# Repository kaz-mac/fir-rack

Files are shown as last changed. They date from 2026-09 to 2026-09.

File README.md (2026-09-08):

# FIR RACK - 3D-printable 10-inch server rack

**English** | [日本語](./README-ja.md)

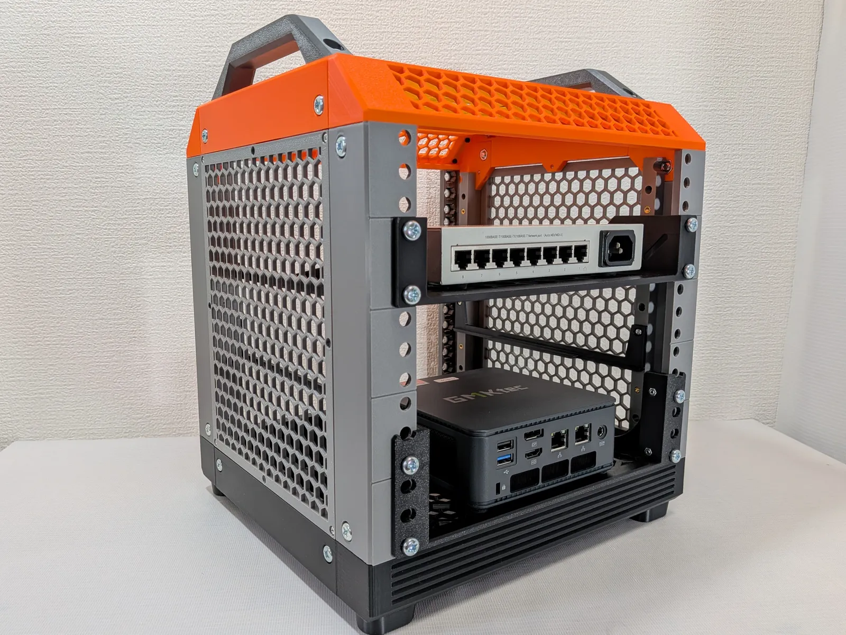
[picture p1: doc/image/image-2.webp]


## Overview

FIR RACK is a remix of [Lab Rax](https://makerworld.com/en/models/1294480-lab-rax-10-server-rack-5u#profileId-1325352) by mklements. It takes after Lab Rax in ease of assembly and overall look, but it was designed from scratch. It is not compatible with Lab Rax.

## Features

FIR RACK keeps what makes Lab Rax great, with these improvements:

* Side panels can be removed without taking the rack apart
* Nuts on the mounting rails are easy to install and remove
* More stable feet
* Deeper frame: 240 mm → 260 mm
* Support rails for heavy shelves (optional)

## Expandability

* **Rack height**<br>
    FIR RACK is 5U. With the extension kit you can add 3U or 5U. For example, adding 3U to a 5U rack gives you an 8U rack.
* **Support rails**<br>
    For heavy shelves, the optional support rails take the load off the mounting rails.

## 4 print profiles

FIR RACK has four profiles. For a minimal rack, the BASIC profile is all you need.

| Profile | What's included | Notes |
|---|---|---|
| BASIC | Core frame parts | Required |
| PANEL | Top, bottom, and side panels | Optional |
| EXTEND | Extension kit parts | Optional |
| RAIL | Support rails | Optional |

## Hardware

Parts you need to assemble FIR RACK:

| Part | Qty | Notes |
|---|---:|---|
| M6 nuts | 24 | Required |
| M6 pan-head screws, 12 mm | 24 | Required |
| M3 nuts | 16 | For side panels (optional) |
| M3 pan-head screws, 12 mm | 16 | For side panels (optional) |
| M6 nuts | 8 | For the extension kit (optional) |
| M6 pan-head screws, 12 mm | 8 | For the extension kit (optional) |
| M3 nuts | 12 | For the extension kit (optional) |
| M3 heat-set inserts (OD 5 mm, length 4 mm) | 32 | For support rails (optional) |
| M3 screws, 5 mm | 12 | For support rails (optional) |

You will also need extra M6 nuts and 12 mm M6 screws for the shelves you install.

### Budget-friendly places to buy

* M6 nuts: [Amazon](https://www.amazon.co.jp/dp/B002A5NN3O)
* M6 pan-head screws, 12 mm: [Amazon](https://www.amazon.co.jp/dp/B002A5MHGS)
* M3 heat-set inserts (OD 5 mm, length 4 mm): [Amazon](https://www.amazon.co.jp/dp/B0F5HMVBWJ) [AliExpress](https://ja.aliexpress.com/item/1005008301059667.html)

## Download the 3D models

FIR RACK is available on MakerWorld.<br>
https://makerworld.com/en/models/3273170-fir-rack-3d-printable-10-inch-server-rack

Shelves can be downloaded from this repository.<br>
[shelf/](shelf/)

If you remix FIR RACK, do not add it as a profile on this model. Publish the remix on your own MakerWorld account.

## Assembly

We recommend printing in PETG. PLA may deform in high heat. See the assembly guide:

Assembly: [English](doc/assembly-en.md) | [日本語](doc/assembly-ja.md)

## Files in GitHub repository

This repository includes:

* [Shelf 3D models](shelf/)

## FIR RACK Satisfactory Kit

A kit of replacement parts that give FIR RACK a [Satisfactory](https://store.steampowered.com/app/526870/Satisfactory/) look. Designed for multi-color printing with AMS. [→ Download](https://makerworld.com/en/models/3277142-fir-rack-satisfactory-kit#profileId-3716643)

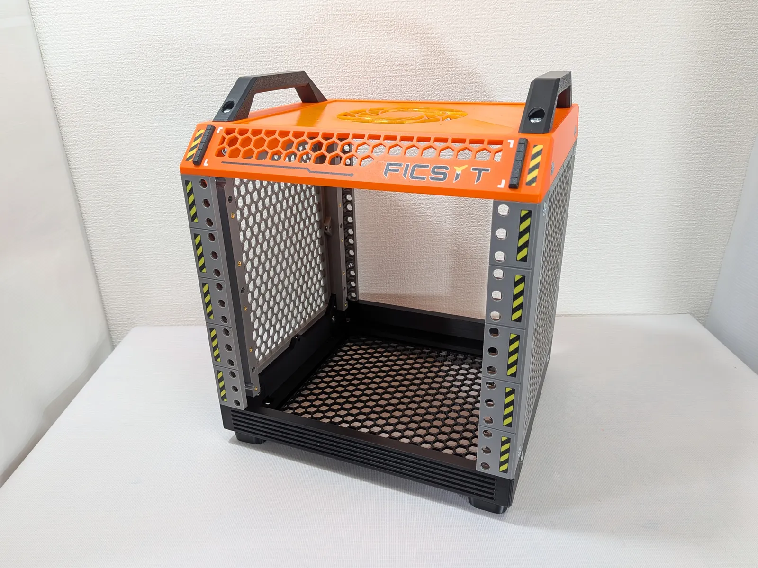
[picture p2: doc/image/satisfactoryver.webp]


## What does FIR RACK stand for?

Factory + Industry + Rig = FIR RACK

## License

The FIR RACK models on MakerWorld are licensed under the [MakerWorld Exclusive License](https://makerworld.com/en/exclusive-model-policy). You may create derivative works based on this object, provided that all such derivative works are published exclusively on the MakerWorld platform and include proper attribution to the original creator. You may not share, upload, host, distribute, or publish this object—or any derivative work of this object—on any other digital platform, marketplace, or distribution channel. Commercial use of this object and any derivative works is strictly prohibited. This includes, but is not limited to, selling, renting, sublicensing, or using the object in any context in which you receive monetary compensation or other financial benefits.

3D models published on GitHub are licensed under CC-BY-SA unless otherwise specified.

## Credits

FIR RACK is a remix of [Lab Rax](https://makerworld.com/en/models/1294480-lab-rax-10-server-rack-5u#profileId-1325352) by mklements. Thanks to mklements for the original design.

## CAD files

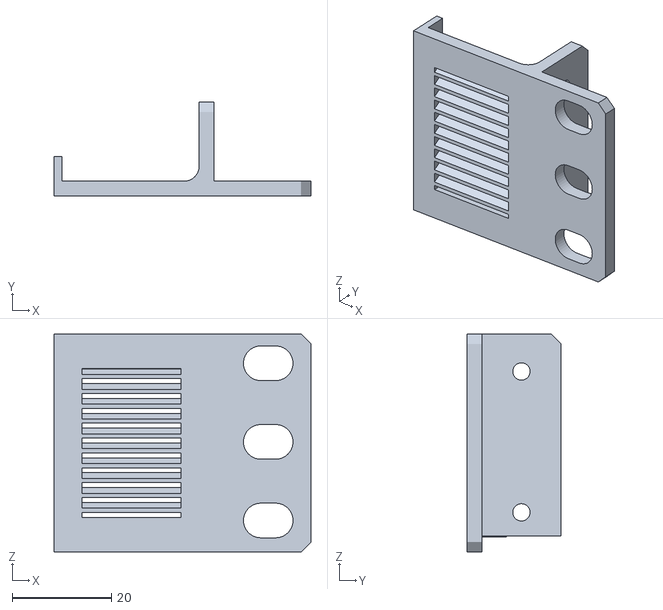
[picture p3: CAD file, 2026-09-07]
shelf/5-inch_drive_1U/1U Ear-R.stl
51.9 x 19.0 x 44.0

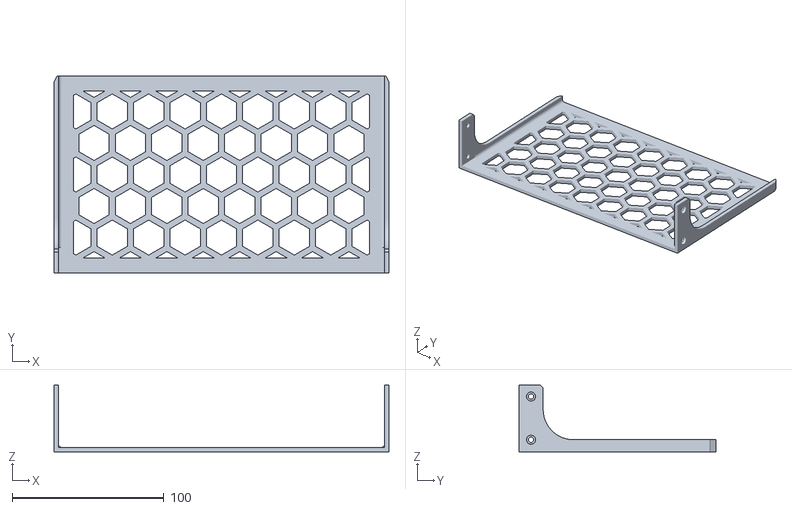
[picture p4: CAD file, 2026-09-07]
shelf/template/depth_130mm/1U Shelf.stl
220.8 x 130.0 x 44.0

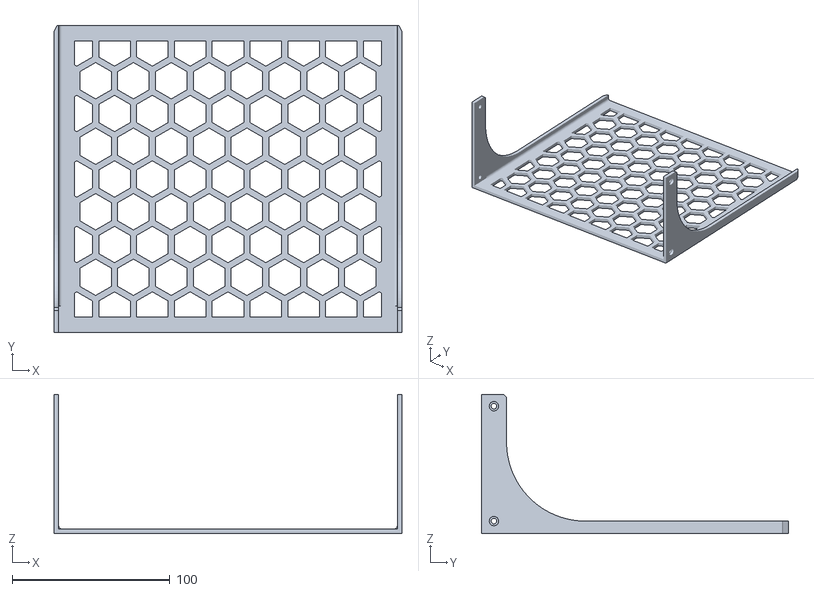
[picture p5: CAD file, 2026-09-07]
shelf/template/depth_195mm/2U Shelf.stl
220.8 x 195.0 x 88.5

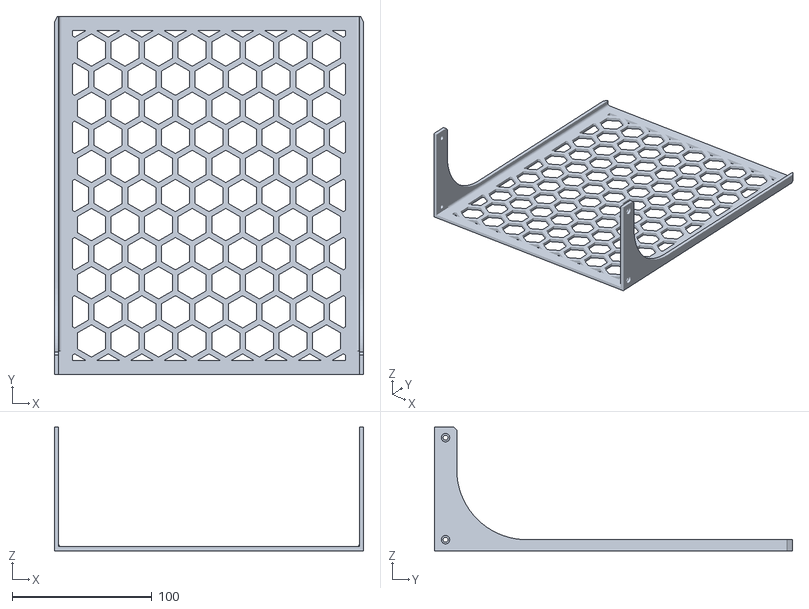
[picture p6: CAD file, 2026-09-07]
shelf/template/depth_256mm/2U Shelf.stl
220.8 x 256.0 x 88.5

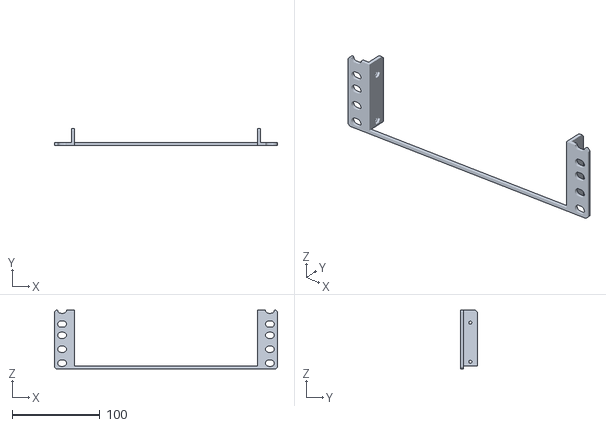
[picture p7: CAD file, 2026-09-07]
shelf/template/depth_260mm/1.5U-DW Ear.stl
253.8 x 19.0 x 66.6

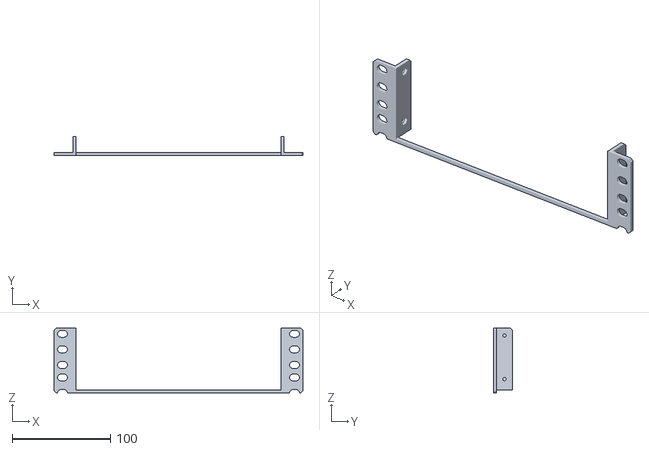
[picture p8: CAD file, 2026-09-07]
shelf/template/depth_130mm/1.5U-UP Ear.stl
253.8 x 19.0 x 66.1

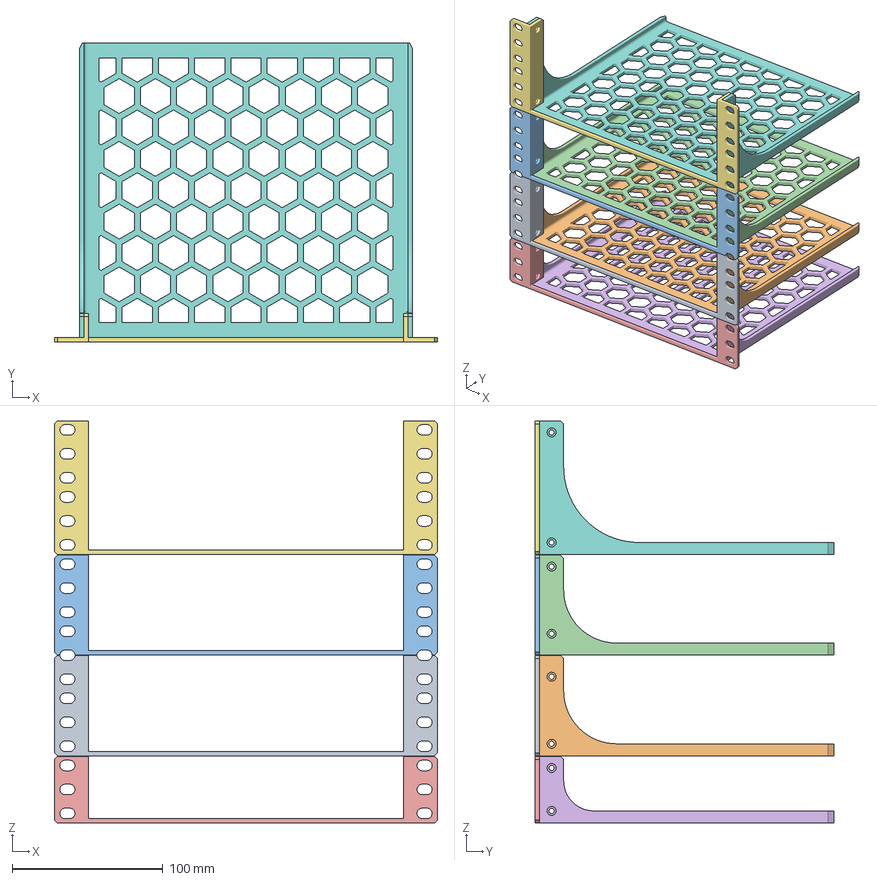
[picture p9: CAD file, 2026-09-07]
shelf/template/depth_195mm/195mm.3mf
253.8 x 198.0 x 266.3 mm
1.5U-DW Ear
1.5U-DW Shelf
1.5U-UP Ear
1.5U-UP Shelf
1U Ear
1U Shelf
2U Ear
2U Shelf

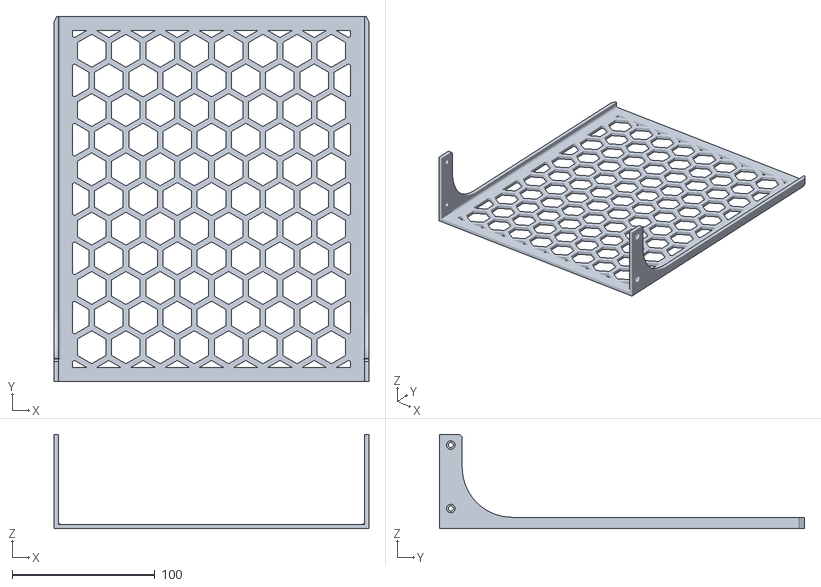
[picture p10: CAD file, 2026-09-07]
shelf/template/depth_256mm/1.5U-UP Shelf.stl
220.8 x 256.0 x 66.1

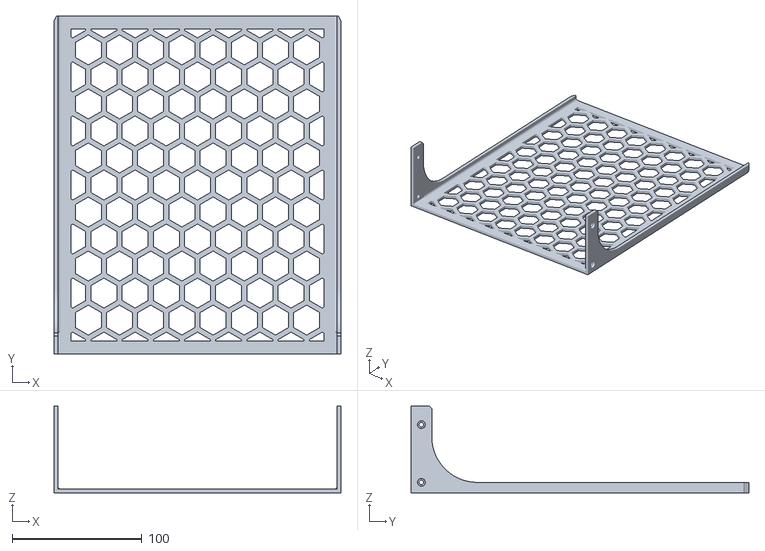
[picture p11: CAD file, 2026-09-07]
shelf/template/depth_260mm/1.5U-DW Shelf.stl
220.8 x 260.0 x 66.6

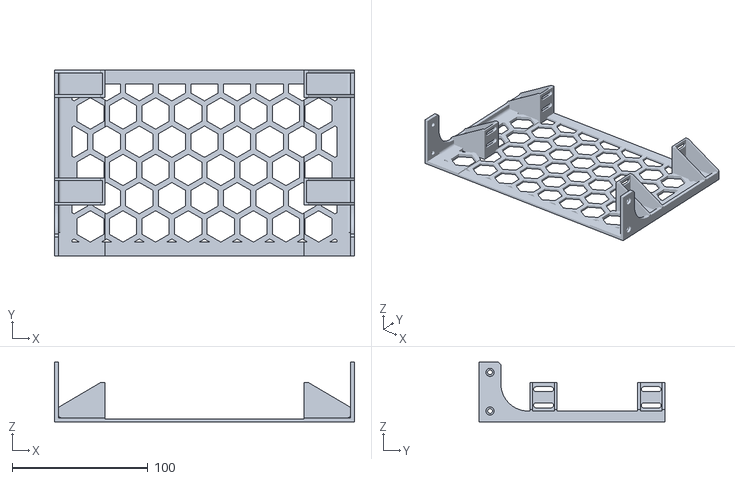
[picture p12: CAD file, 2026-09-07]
shelf/5-inch_drive_1U/1U Shelf.stl
220.8 x 136.6 x 44.0

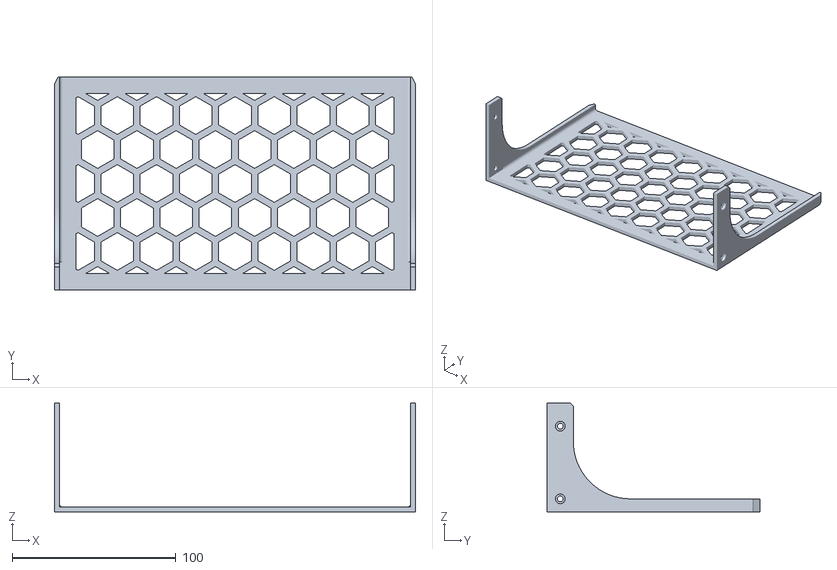
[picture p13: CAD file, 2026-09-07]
shelf/template/depth_130mm/1.5U-DW Shelf.stl
220.8 x 130.0 x 66.6

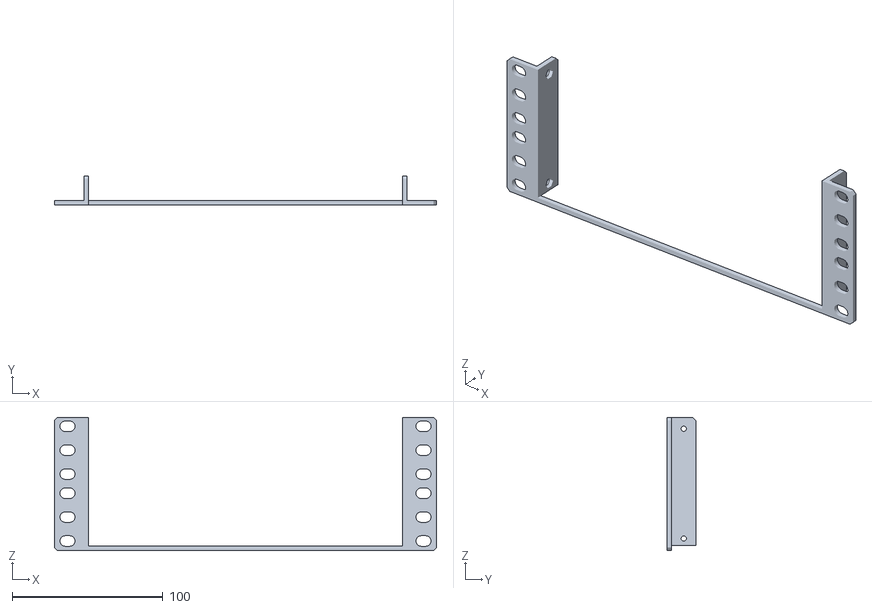
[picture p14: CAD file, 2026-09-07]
shelf/template/depth_195mm/2U Ear.stl
253.8 x 19.0 x 88.5

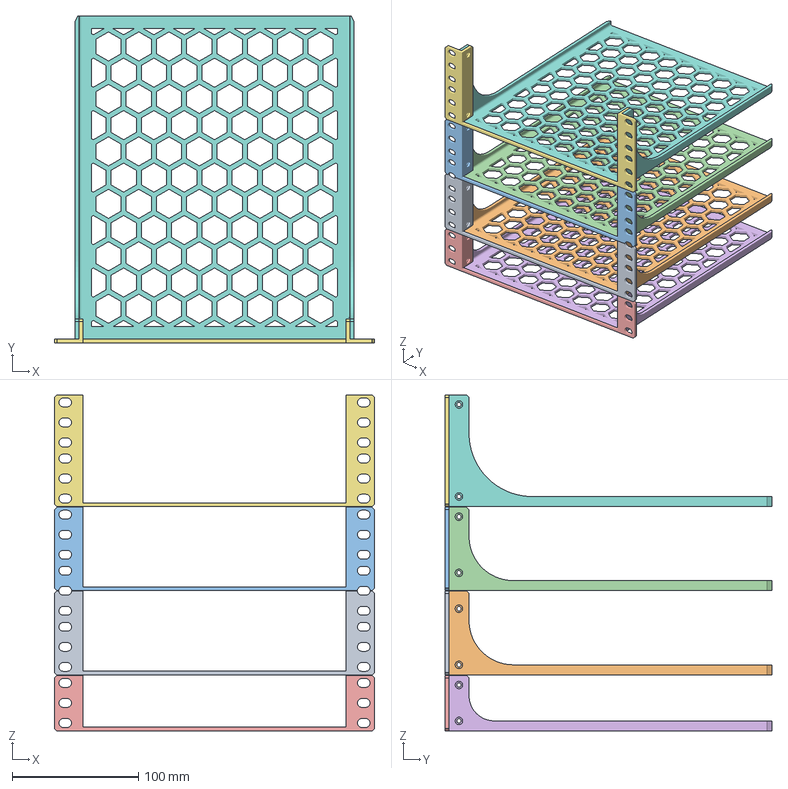
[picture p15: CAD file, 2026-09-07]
shelf/template/depth_256mm/256mm.3mf
253.8 x 259.0 x 266.3 mm
1.5U-DW Ear
1.5U-DW Shelf
1.5U-UP Ear
1.5U-UP Shelf
1U Ear
1U Shelf
2U Ear
2U Shelf

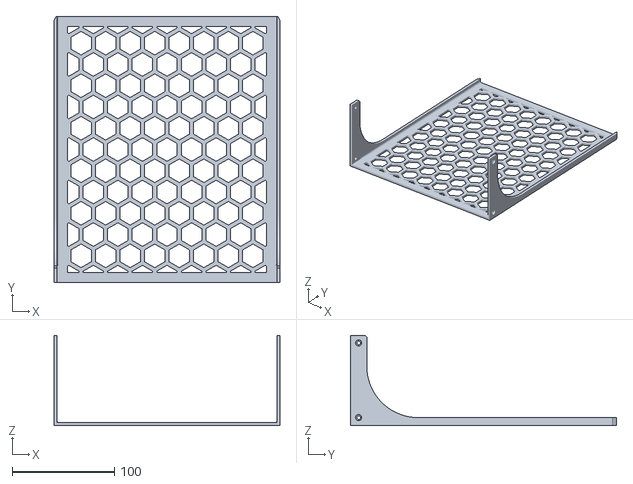
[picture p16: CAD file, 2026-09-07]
shelf/template/depth_260mm/2U Shelf.stl
220.8 x 260.0 x 88.5

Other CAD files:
shelf/5-inch_drive_1U/1U Ear-L.stl
shelf/template/depth_130mm/2U Shelf.stl
shelf/template/depth_195mm/1U Shelf.stl
shelf/template/depth_256mm/2U Ear.stl
shelf/template/depth_130mm/1.5U-DW Ear.stl
shelf/template/depth_130mm/1.5U-UP Shelf.stl
shelf/template/depth_130mm/130mm.3mf
shelf/template/depth_130mm/1U Ear.stl
shelf/template/depth_130mm/2U Ear.stl
shelf/template/depth_195mm/1.5U-DW Ear.stl
shelf/template/depth_195mm/1.5U-DW Shelf.stl
shelf/template/depth_195mm/1.5U-UP Ear.stl
shelf/template/depth_195mm/1.5U-UP Shelf.stl
shelf/template/depth_195mm/1U Ear.stl
shelf/template/depth_256mm/1.5U-DW Ear.stl
shelf/template/depth_256mm/1.5U-DW Shelf.stl
shelf/template/depth_256mm/1.5U-UP Ear.stl
shelf/template/depth_256mm/1U Ear.stl
shelf/template/depth_256mm/1U Shelf.stl
shelf/template/depth_260mm/1.5U-UP Ear.stl
shelf/template/depth_260mm/1.5U-UP Shelf.stl
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

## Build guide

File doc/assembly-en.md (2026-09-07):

# FIR RACK assembly guide

Assembly: **English** | [日本語](./assembly-ja.md)

We recommend printing in PETG. PLA may deform in high heat.

## 4 profiles

The parts you print depend on how you want to build your rack. When you open the 3MF in Bambu Studio, the top of each plate shows print quantities and other notes — use that as a reference.

### (1) BASIC profile

All of the core frame parts are in the BASIC profile.

| File name | Description | Qty | Notes |
|---|---|---:|---|
| X Edge Top | Horizontal frame, top | 2 |  |
| X Edge Bottom | Horizontal frame, bottom | 2 |  |
| Y Edge | Depth frame (rear) | 4 |  |
| Z Edge 5U | Vertical mounting rail | 4 |  |
| Handle | Handle | 2 |  |
| Foot | Foot | 4 |  |

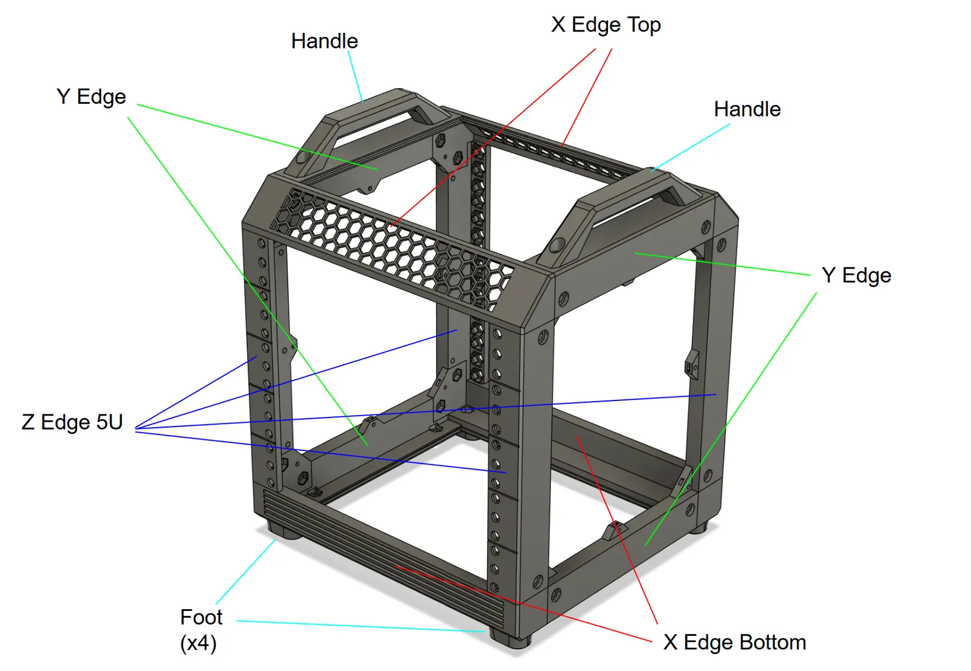
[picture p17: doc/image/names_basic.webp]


### (2) PANEL profile (optional)

Panels are in a separate profile. Print what you need from the PANEL profile.

| File name | Description |
|---|---|
| TB Panel 12cm-fan | Top/bottom panel (120 mm fan) |
| TB Panel 14cm-fan | Top/bottom panel (140 mm fan) |
| TB Panel mesh | Top/bottom panel (mesh) |
| TB Panel plane | Top/bottom panel (solid) |
| LR Panel mesh 5U | Side panel (mesh) |
| LR Panel plane 5U | Side panel (solid) |

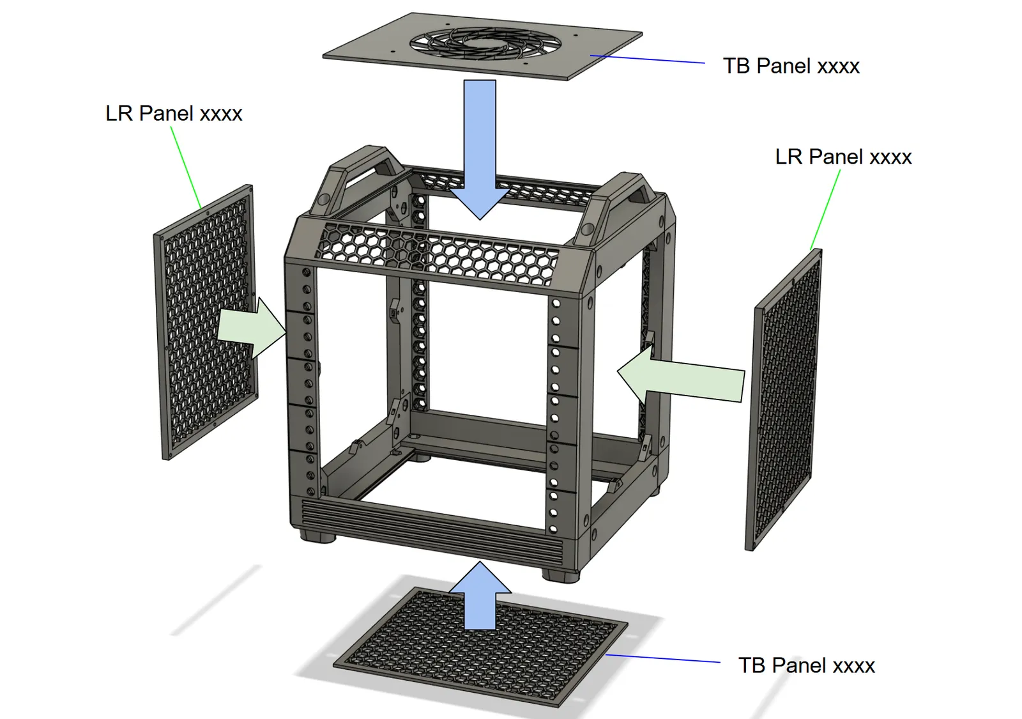
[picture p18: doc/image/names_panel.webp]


### (3) EXTEND profile (optional)

To add 3U or 5U of height, print what you need from the EXTEND profile. Parts labeled "3U" are for a 3U extension. For a 5U extension, use parts from BASIC and PANEL.

| File name | Description | 3U | 5U |
|---|---|---:|---:|
| Extend Unit | Extension unit | 2 | 2 |
| Extend Unit-cover | Extension unit screw covers | 6 | 6 |
| Z Edge 3U | Vertical mounting rail, 3U | 4 |  |
| Rail Holder-L 3U | Support rail bracket, left, 3U | (2) *1 |  |
| Rail Holder-R 3U | Support rail bracket, right, 3U | (2) *1 |  |
| LR Panel mesh 3U | Side panel (mesh), 3U | (2) |  |
| LR Panel plane 3U | Side panel (solid), 3U | (2) |  |

Note: *1 ... Print only if you use support rails

For details, see [Assembling the extension kit](#assembling-the-extension-kit) in this guide.

### (4) RAIL profile (optional)

Support rails are optional. They can hold heavy shelves, but only certain shelves will fit. See [Using the support rails](#using-the-support-rails-optional) in this guide.

| File name | Description | Qty | Notes |
|---|---|---:|---|
| Rail Holder-L 5U | Support rail bracket, left | (2) | *1 |
| Rail Holder-R 5U | Support rail bracket, right | (2) | *1 |
| Rail-1U | Support rail (1U) | (2 per U) | *1 |
| Rail-1.5U | Support rail (1.5U) | (2 per U) | *1 |

Note: *1 ... Print only if you use support rails

For details, see [Using the support rails](#using-the-support-rails-optional) in this guide.

## STEP 1 Installing the nuts

After printing, take the X Edge Top/Bottom, Y Edge, and Z Edge 5U parts.
Press-fit the M3 nuts used to mount the panels.

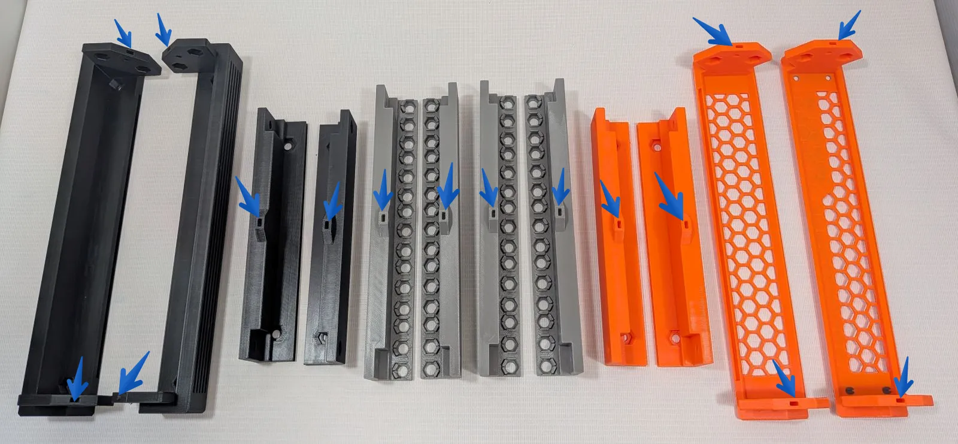
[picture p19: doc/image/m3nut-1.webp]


Push them all the way in with a flat-head screwdriver or a thin rod.

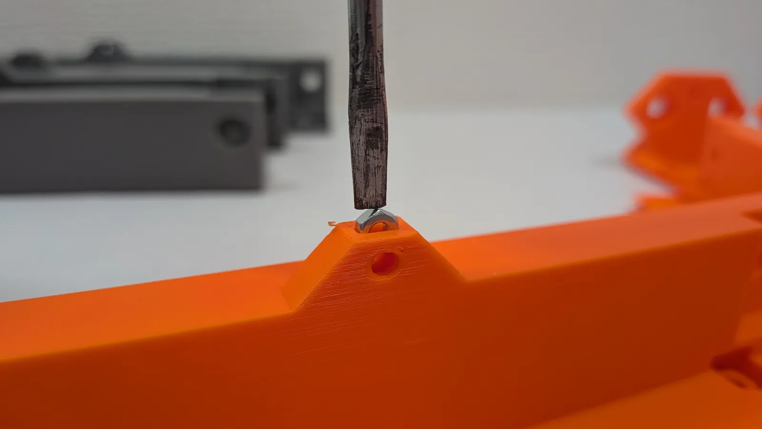
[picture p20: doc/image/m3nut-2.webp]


## STEP 2 Assembling the bottom

Assemble the bottom frame. Fit X Edge Bottom and Y Edge together, and slide in the TB Panel you chose. Watch the direction of the panel grooves. Once everything is seated, fasten with M6 nuts and M6 screws. If a nut is too tight, use pliers. If it is loose, a small amount of glue helps.

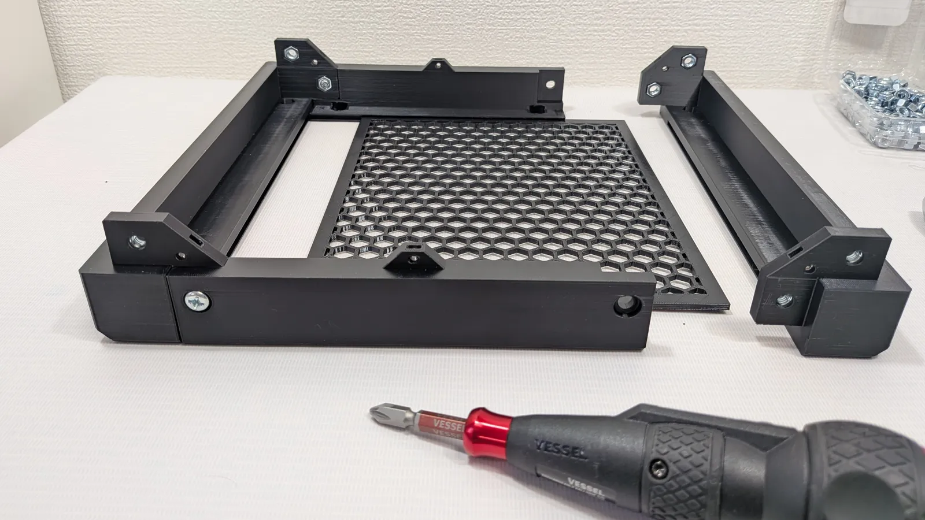
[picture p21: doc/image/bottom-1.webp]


Flip it over and install the Foot parts. Do not use the inner holes.

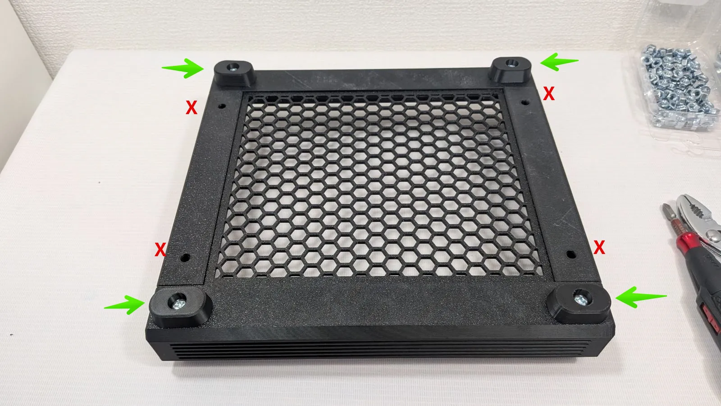
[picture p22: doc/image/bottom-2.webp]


## STEP 3 Assembling the top

Assemble the top frame. Fit X Edge Top and Y Edge together, and slide in the TB Panel you chose.

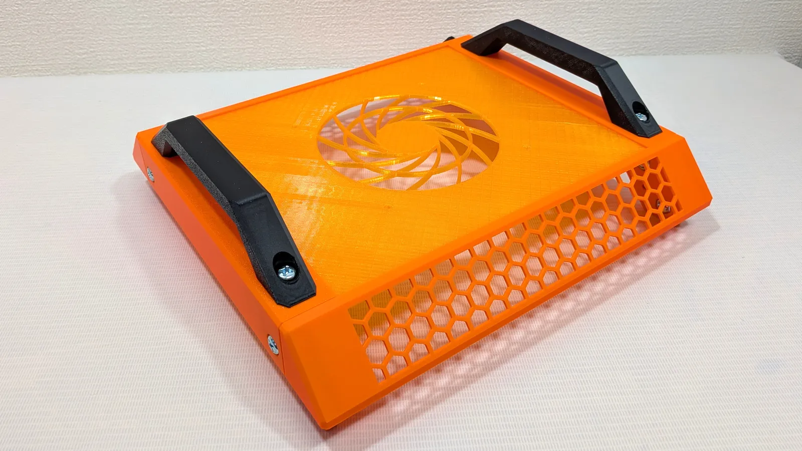
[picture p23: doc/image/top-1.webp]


Then install the Handle parts.

## STEP 4 Support rails (optional)

If you are not using support rails, skip to STEP 5. Support rails can hold heavy shelves. If you use them, you need to prep the mounting rails before final assembly.

### Installing heat-set inserts

Install heat-set inserts in Z Edge 5U, Rail Holder-L 5U, and Rail Holder-R 5U. Use the smaller holes.

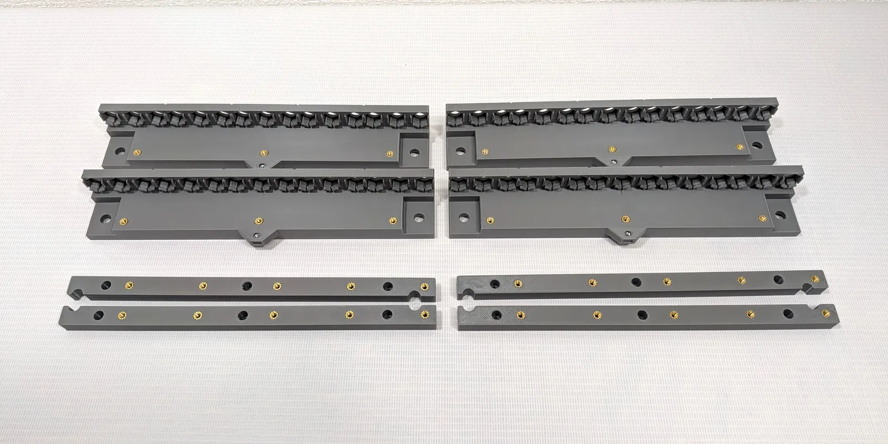
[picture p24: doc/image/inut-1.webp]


Insert size: ID 3 mm, OD 5 mm, length 4 mm

### Attaching the rail holders

Attach the Rail Holder-* 5U parts to Z Edge 5U. Fasten with M3 × 5 mm screws. Watch the orientation: arrange them as in the photo, with the ▼ marks pointing down.

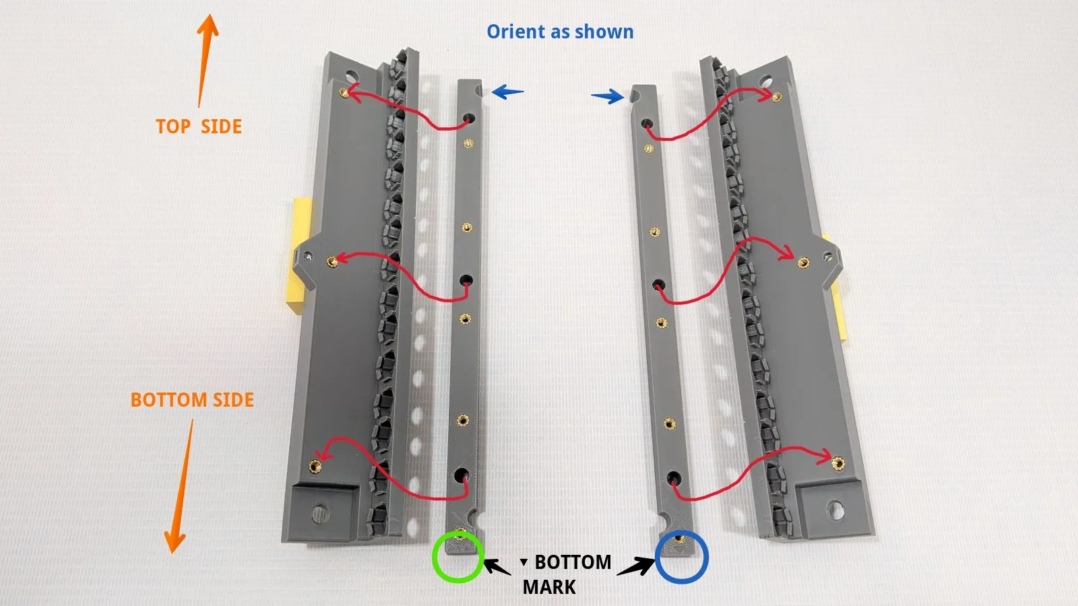
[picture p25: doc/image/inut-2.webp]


Finished assembly:

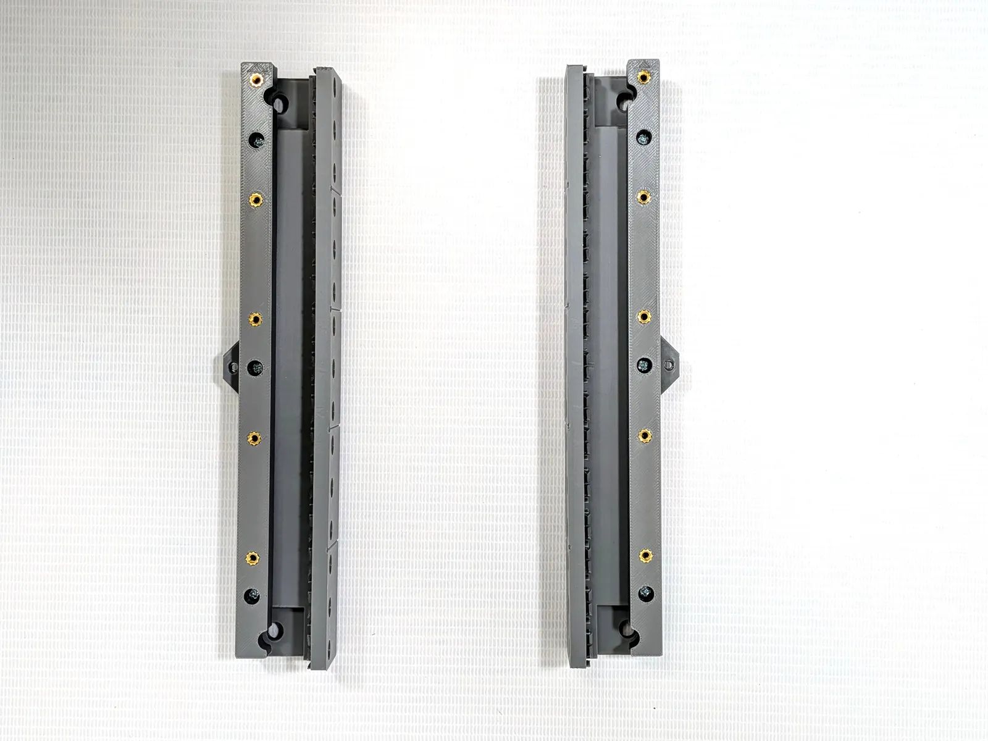
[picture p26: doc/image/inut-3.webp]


If the M6 screw holes are blocked, the parts are on the wrong side. Compare with the photo and flip them.

## STEP 5 Putting the rack together

Connect the bottom frame to the mounting rails (Z Edge 5U) with M6 × 12 mm screws. Insert the nuts first, set the rail position, then tighten the screws.

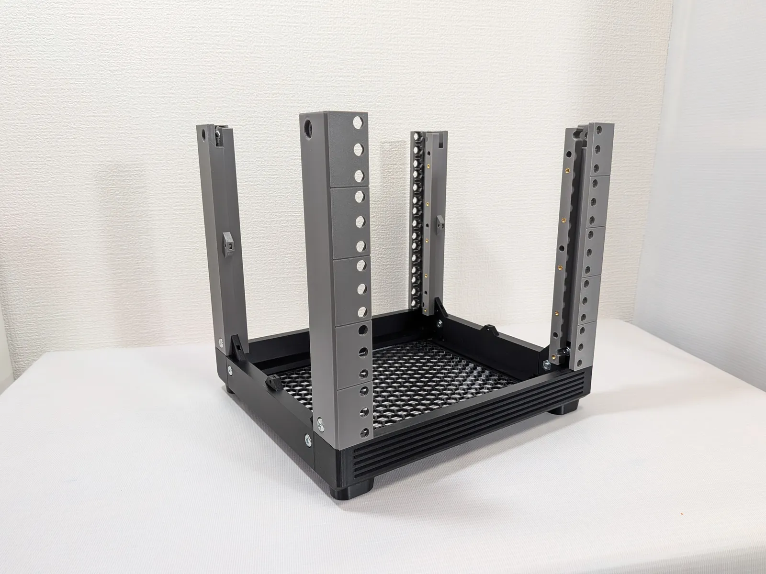
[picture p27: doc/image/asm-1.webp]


If you use support rails, keep the ▼ marks pointing down. If you do not, either end up is fine.

Install the top frame the same way.

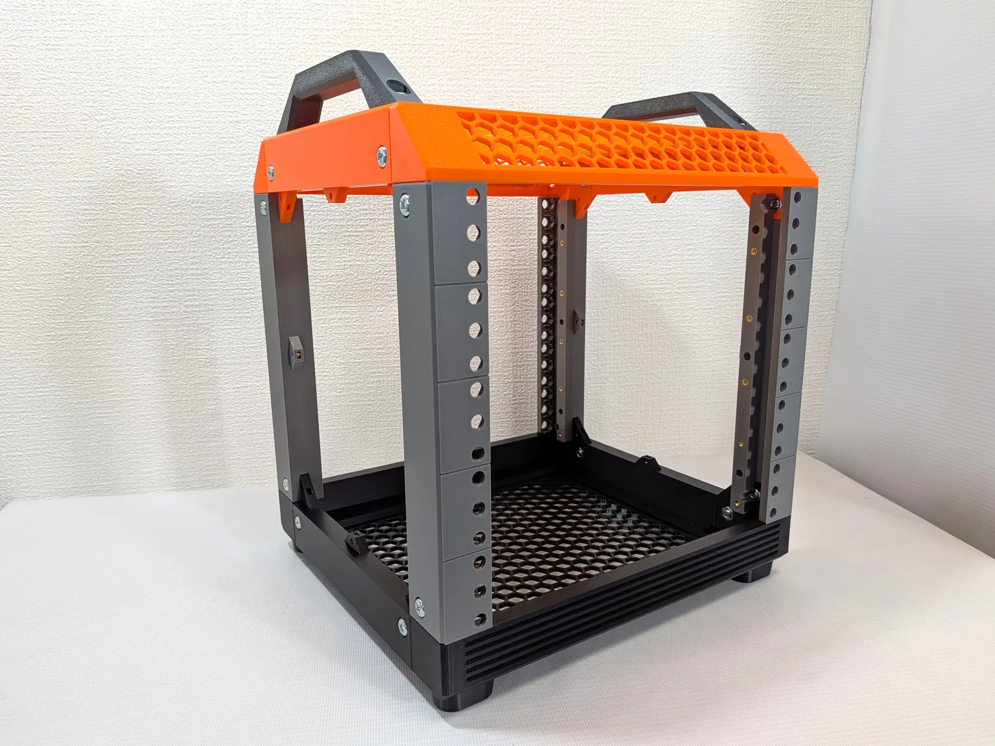
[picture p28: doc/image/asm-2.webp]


## STEP 6 Side panels (optional)

If you use side panels, fasten them to the frame with M3 × 12 mm screws.

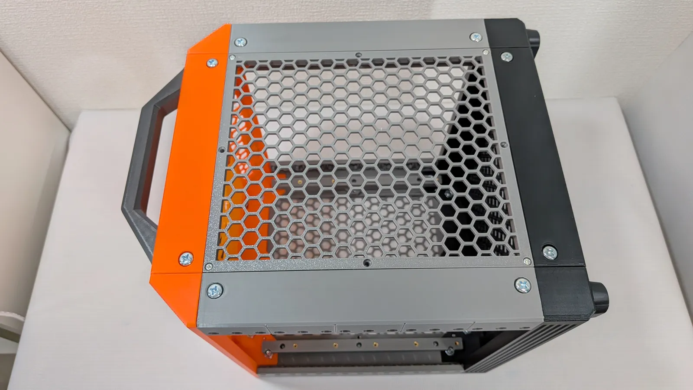
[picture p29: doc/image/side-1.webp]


## Done!

Congratulations — your server rack is finished.

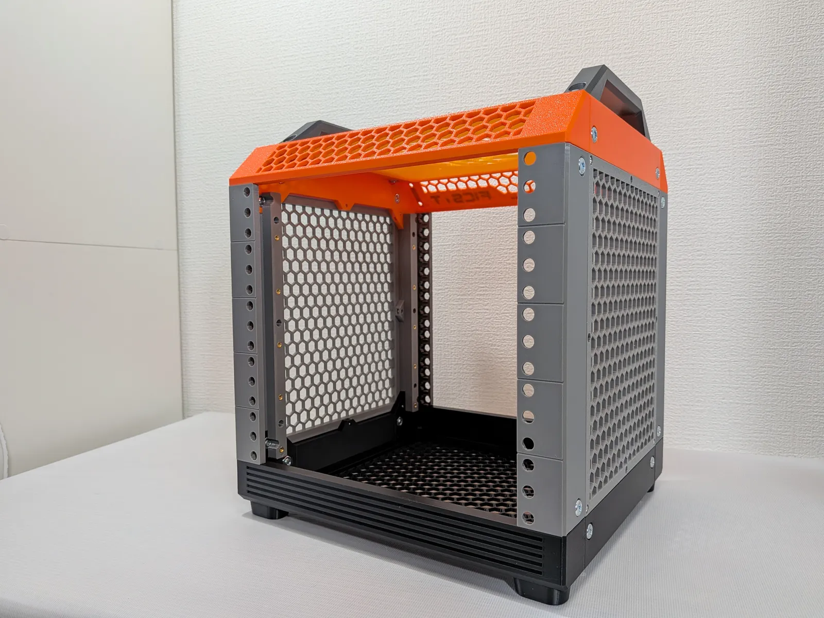
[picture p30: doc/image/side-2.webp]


Enjoy your homelab!

## Installing cage nuts

Install M6 nuts in the mounting rails. Slide each nut in from the side and press with your finger until it clicks into the hole.

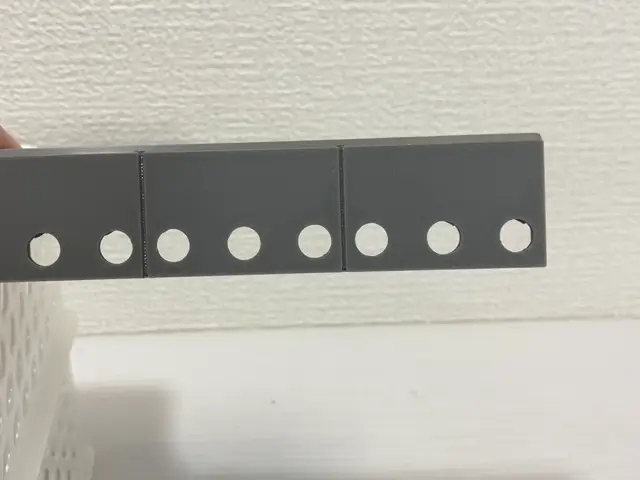
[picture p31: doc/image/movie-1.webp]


When you mount gear with M6 screws, do not push the screw in hard. Too much force will pop the nut out.

## Assembling the extension kit

This example adds 3U. Print the parts from the EXTEND profile. Press-fit M3 nuts into the Extend Unit, then install the covers. Also install the M6 nuts.

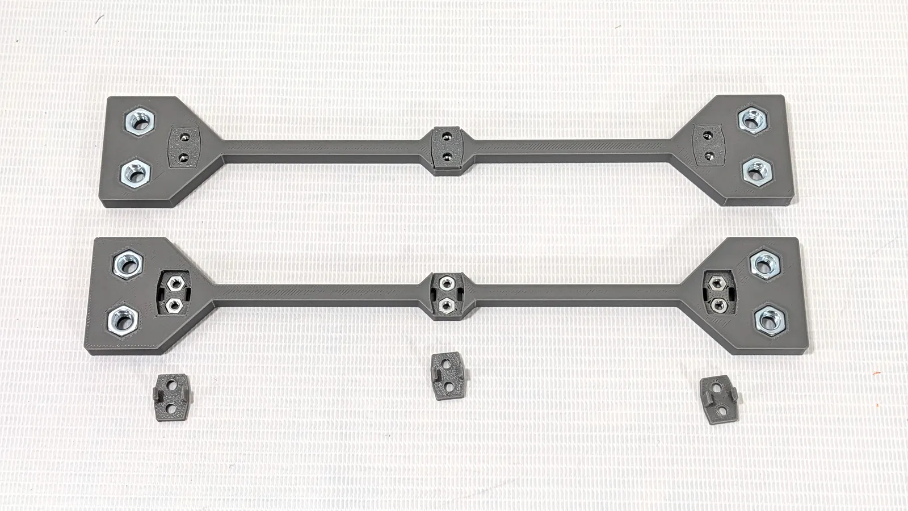
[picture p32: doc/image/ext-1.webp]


Remove the top, and attach the Extend Unit parts to the mounting rails. Orient them as shown in the photo.

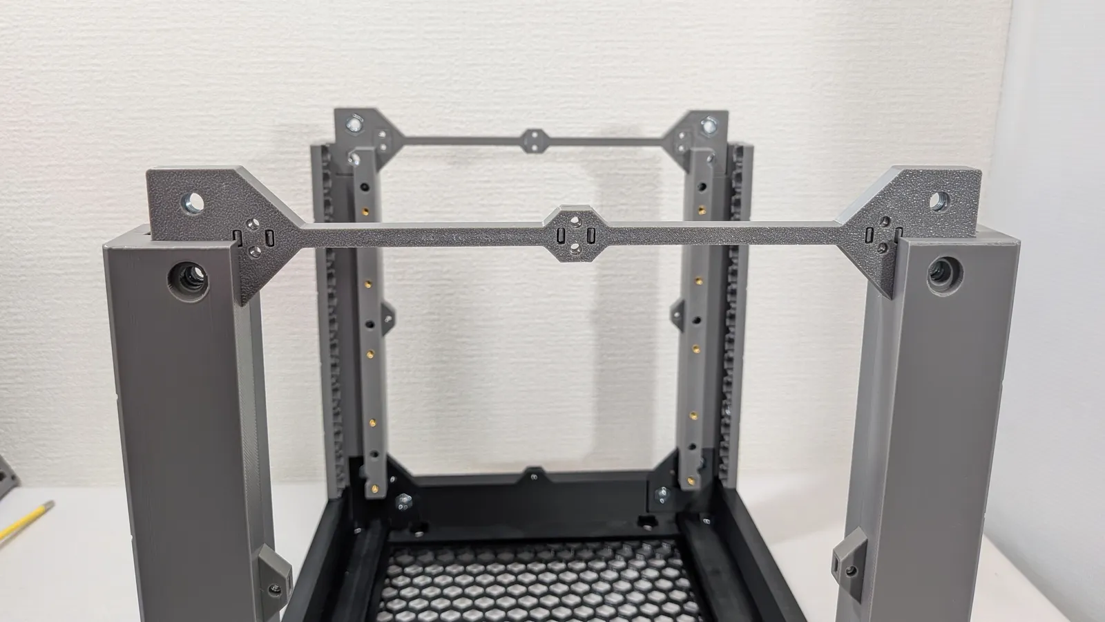
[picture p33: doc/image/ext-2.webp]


Install the extra mounting rails. If you use the optional support rails, attach those first.

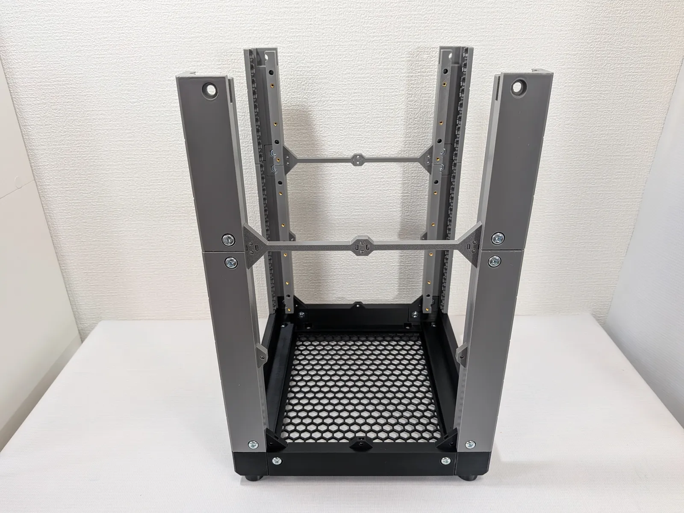
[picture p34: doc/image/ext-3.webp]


Put the top back on to finish.

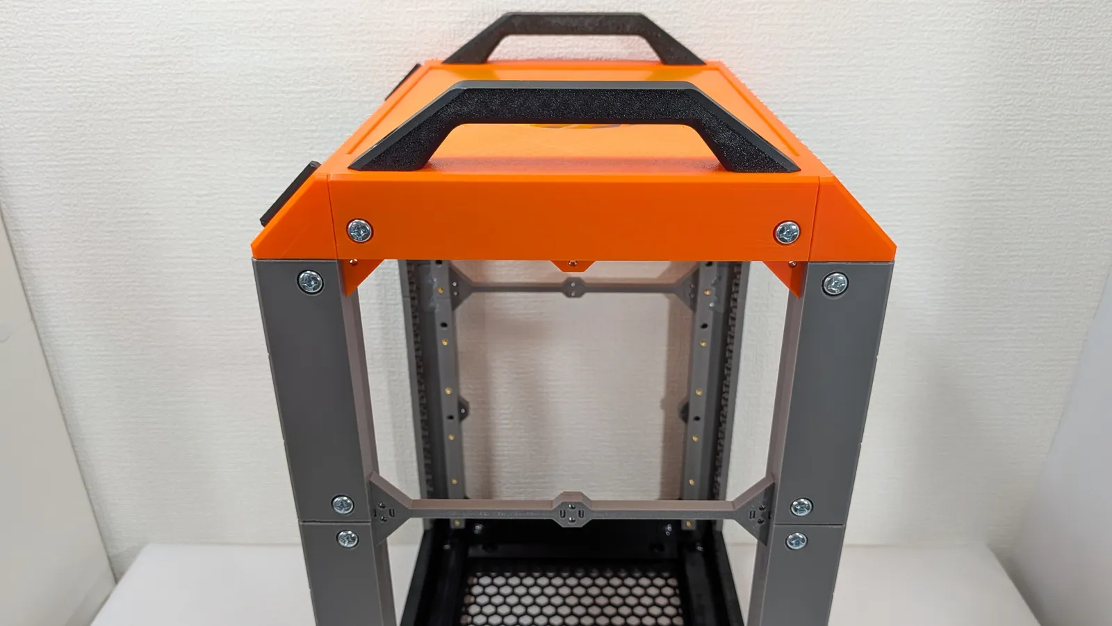
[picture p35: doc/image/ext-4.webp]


If you use side panels, install them last.

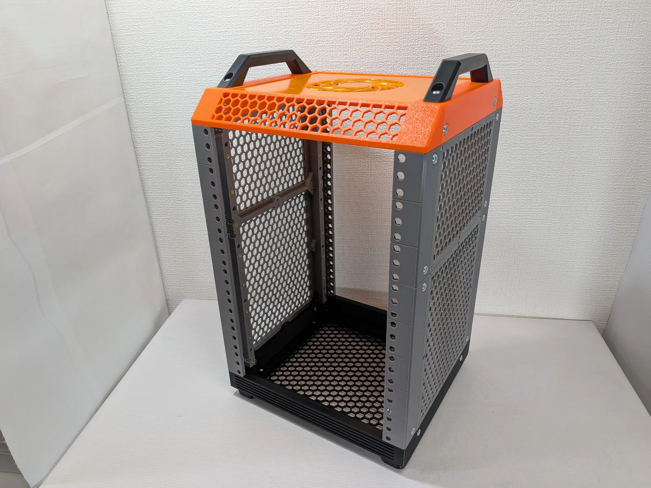
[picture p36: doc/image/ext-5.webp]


## Using the support rails (optional)

Support rails are optional. They can hold heavy shelves, but only certain shelves will fit.

### Compatible shelves

* Width: 215 mm or more
* Depth: 90 mm or more

### Shelf 3D models

The following models are included:

* [Templates](../shelf/template/)  
  (The front panel area is left blank. Modify it to suit your needs.)
* [5.25-inch drive](../shelf/5-inch_drive_1U/)

### Installing the support rails

Fasten Rail-1U with M3 × 5 mm screws. For a 1.5U shelf, use Rail-1.5U.

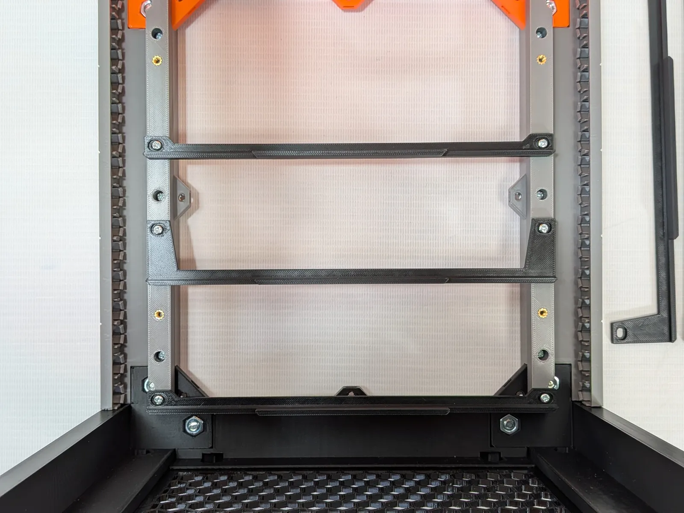
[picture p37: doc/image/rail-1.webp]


The shelf sits on the support rails, so heavy gear does not load the mounting rails.

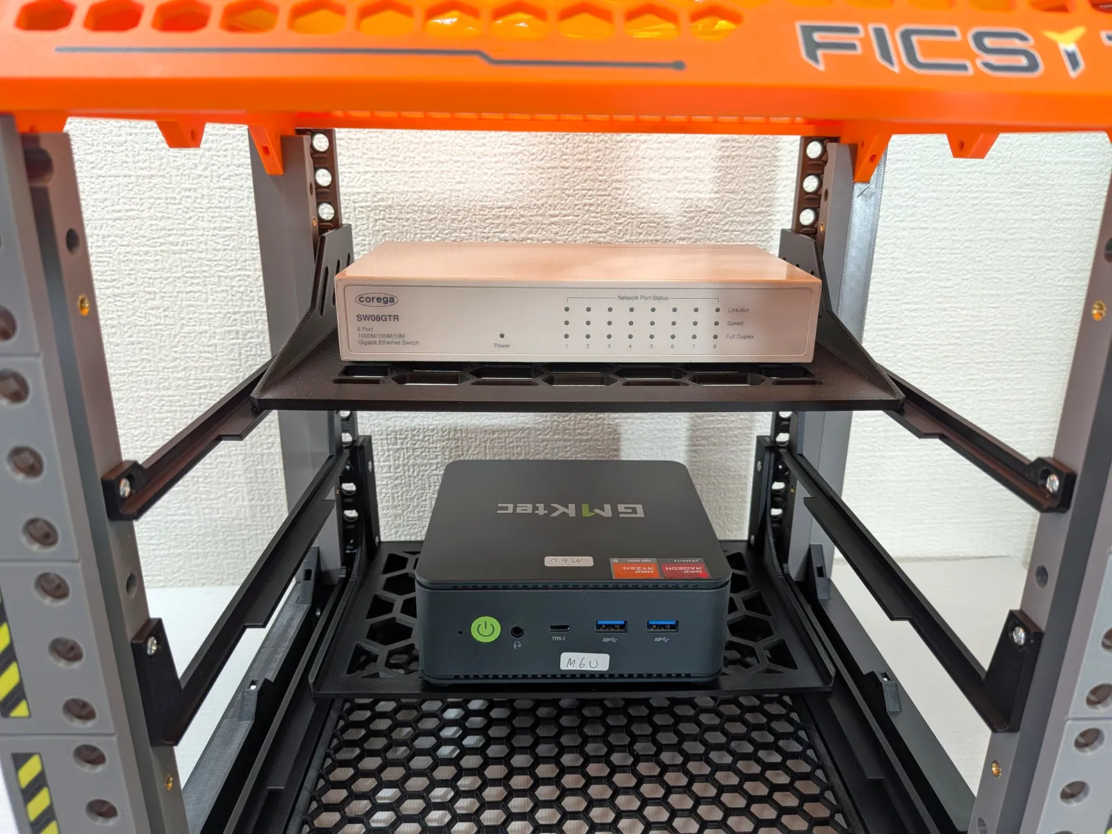
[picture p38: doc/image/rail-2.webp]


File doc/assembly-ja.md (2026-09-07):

# FIR RACK 組み立て手順

組み立て手順: [English](./assembly-en.md) | **日本語**

フィラメントは PETG でプリントすることをおすすめします。PLA は高温により変形する恐れがあります。

## 4つのプロファイル

作成するラックの構成によって、プリントするパーツの種類や個数が変わります。Bambu Studioで3MFファイルを開くと、プレート上部にプリント数などの情報が記載されているので参考にしてください。

### (1) BASICプロファイル

基本のパーツはBASIC Profileに全て納められています。

| ファイル名 | 部位 | 数量 | 備考 |
|---|---|---:|---|
| X Edge Top | 支柱 (水平方向) 上 | 2 |  |
| X Edge Bottom | 支柱 (水平方向) 下 | 2 |  |
| Y Edge | 支柱 (奥方向) | 4 |  |
| Z Edge 5U | 支柱 (垂直方向) | 4 |  |
| Handle | 取っ手 | 2 |  |
| Foot | 足 | 4 |  |



### (2) PANELプロファイル (optional)

パネルは別プロファイルになっています。PANEL Profileから必要なものをプリントしてください。

| ファイル名 | 部位 |
|---|---|
| TB Panel 12cm-fan | 上下パネル (12cm FAN用) |
| TB Panel 14cm-fan | 上下パネル (14cm FAN用) |
| TB Panel mesh | 上下パネル (メッシュ) |
| TB Panel plane | 上下パネル (プレーン) |
| LR Panel mesh 5U | 左右パネル (メッシュ) |
| LR Panel plane 5U | 左右パネル (プレーン) |



### (3) 延長プロファイル (optional)

3Uまたは5Uの延長をしたい場合はExtend Profileから必要なものをプリントしてください。"3U"と書かれたパーツは3Uの延長用です。5Uの延長をする場合はBASICやPANEL内のパーツを使ってください。

| ファイル名 | 部位 | 3U | 5U |
|---|---|---:|---:|
| Extend Unit | 延長ユニット | 2 | 2 |
| Extend Unit-cover | 延長ユニットねじ蓋 | 6 | 6 |
| Z Edge 3U | 支柱 (垂直) 3U | 4 |  |
| Rail Holder-L 3U | サポートレール固定 左 3U | (2) *1 |  |
| Rail Holder-R 3U | サポートレール固定 右 3U | (2) *1 |  |
| LR Panel mesh 3U | 左右パネル (メッシュ) 3U | (2) |  |
| LR Panel plane 3U | 左右パネル (プレーン) 3U | (2) |  |

注: *1 ... サポートレールを使用する場合のみプリント

延長について詳しくは、本ドキュメントの「延長オプションの組み立て方法」をご覧ください。

### (4) レールプロファイル (optional)

サポートレールのプリントは任意です。サポートレールを使用すると重いシェルフを支えることができますが、使用できるシェルフに制限があります。詳しくはこのドキュメントの「サポートレールの使い方」をご覧ください。

| ファイル名 | 場所 | 数量 | 備考 |
|---|---|---:|---|
| Rail Holder-L 5U | サポートレール固定 左 | (2) | *1 |
| Rail Holder-R 5U | サポートレール固定 右 | (2) | *1 |
| Rail-1U | サポートレール (1U) | (2xUnit) | *1 |
| Rail-1.5U | サポートレール (1.5U) | (2xUnit) | *1 |

注: *1 ... サポートレールを使用する場合のみプリント

サポートレールについて詳しくは、本ドキュメントの「サポートレールの使い方」をご覧ください。

## STEP 1 ナット埋め込み

必要なパーツのプリントが終わったら、"X Edge Top/Bottom" と "Y Edge" と "Z Edge 5U" を用意します。
これらにパネル取り付け用のM3ナットを埋め込みます。



マイナスドライバーや細い棒で奥まで押し込みます。



## STEP 2 底面の組み立て

底面部分を組み立てます。"X Edge Bottom" と "Y Edge" を組み合わせ、中に選択した "TB Panel xxxx" を入れます。パネル用の溝の向きに注意してください。位置の確認ができたら、M6ナットとM6ねじで固定します。ナットがきつい場合はペンチを使用してください。緩い場合は少量の接着剤を付けておくと便利です。



裏返して "Foot" を取り付けます。内側の穴は使用しません。



## STEP 3 屋根の組み立て

屋根部分を組み立てます。"X Edge Top" と "Y Edge" を組み合わせ、中に "TB Panel xxxx" を入れます。



組み立てたら "Handle" を取り付けます。

## STEP 4 サポートレール (optional)

サポートレールを使用しない場合は STEP 5 に進んでください。サポートレールを使用すると重いシェルフを支えることができます。サポートレールを使用する場合は、マウントレールを取り付ける前に加工が必要です。

### インサートナットの取り付け

"Z Edge 5U" と "Rail Holder-L 5U" と "Rail Holder-R 5U" にインサートナットを取り付けます。インサートナットを付けるのは小さいほうの穴です。



インサートナットのサイズ: ID 3mm, OD 5mm, Length 4mm

### 結合

"Z Edge 5U" に "Rail Holder-* 5U" を取り付けます。5mmのM3ねじで固定します。向きに注意してください。写真のように配置して、"▼"マークが書かれた部分を下にしてください。



完成写真。



M6ねじ穴が塞がれている場合は位置が逆ですので、写真のように配置して確認してください。

## STEP 5 組み立て

底面部分とマウントレール "Z Edge 5U" を、M6ねじ(12mm)で接続します。先にナットを入れて、マウントレールの位置を決めたらネジで固定します。



サポートレールを使用する場合は、"▼"マークが書かれた部分を下にしてください。サポートレールを使用しない場合は、上下の向きはどちらでもかまいません。

同様に屋根部分を取り付けます。



## STEP 6 サイドパネル (optional)

サイドパネルを使用する場合は、本体にM3ねじ(12mm)で固定します。



## 完成!

おめでとうございます！あなただけのサーバーラックが完成しました。



素敵な自宅鯖ライフをお楽しみください！

## ケージナットの固定方法

マウントレールにM6ナットを取り付けます。ナットは横方向から入れて指で押すと、カチッと穴に固定されます。



機器をM6ねじで固定するときは、ねじを強く押さないように注意してください。力を入れるとナットが外れます。

## 延長オプションの組み立て方法

ここでは例として、3Uを延長する手順を説明します。延長用プロファイルのパーツのプリントをします。"Extend Unit" にM3ナットを埋め込み、蓋をします。M6ナットも取り付けます。



屋根を外し、"Extend Unit" をマウントレールに取り付けます。向きを写真のようにしてください。



延長用のマウントレールを取り付けます。オプションのサポートレールを使用する場合は、先に取り付けておく必要があります。



最後に屋根を載せて完成です。



サイドパネルを使用する場合は、一番最後に取り付けます。



## サポートレールの使い方 (optional)

サポートレールのプリントは任意です。サポートレールを使用すると重いシェルフを支えることができますが、使用できるシェルフに制限があります。

### 使用可能なシェルフの条件

* 横幅: 215mm 以上
* 奥行: 90mm 以上

### シェルフの3Dモデル

以下の3Dモデルを配布しています。

* [各種テンプレート](../shelf/template/)
    （フロントパネルの部分が空です。ご自身で加工してご使用ください。）
* [5インチドライブ用](../shelf/5-inch_drive_1U/)

### サポートレールの固定方法

"Rail-1U" をM3ねじ(5mm)で固定します。1.5Uのシェルフを設置する場合は "Rail-1.5U" を使用します。



シェルフがサポートレールの上に乗るので、重い荷物が乗ってもマウントレールに負担がかかりません。
